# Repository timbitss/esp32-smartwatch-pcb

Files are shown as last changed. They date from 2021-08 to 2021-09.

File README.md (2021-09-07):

# ESP32 Smartwatch PCB

## Blinky Test

Blinky

## Schematic

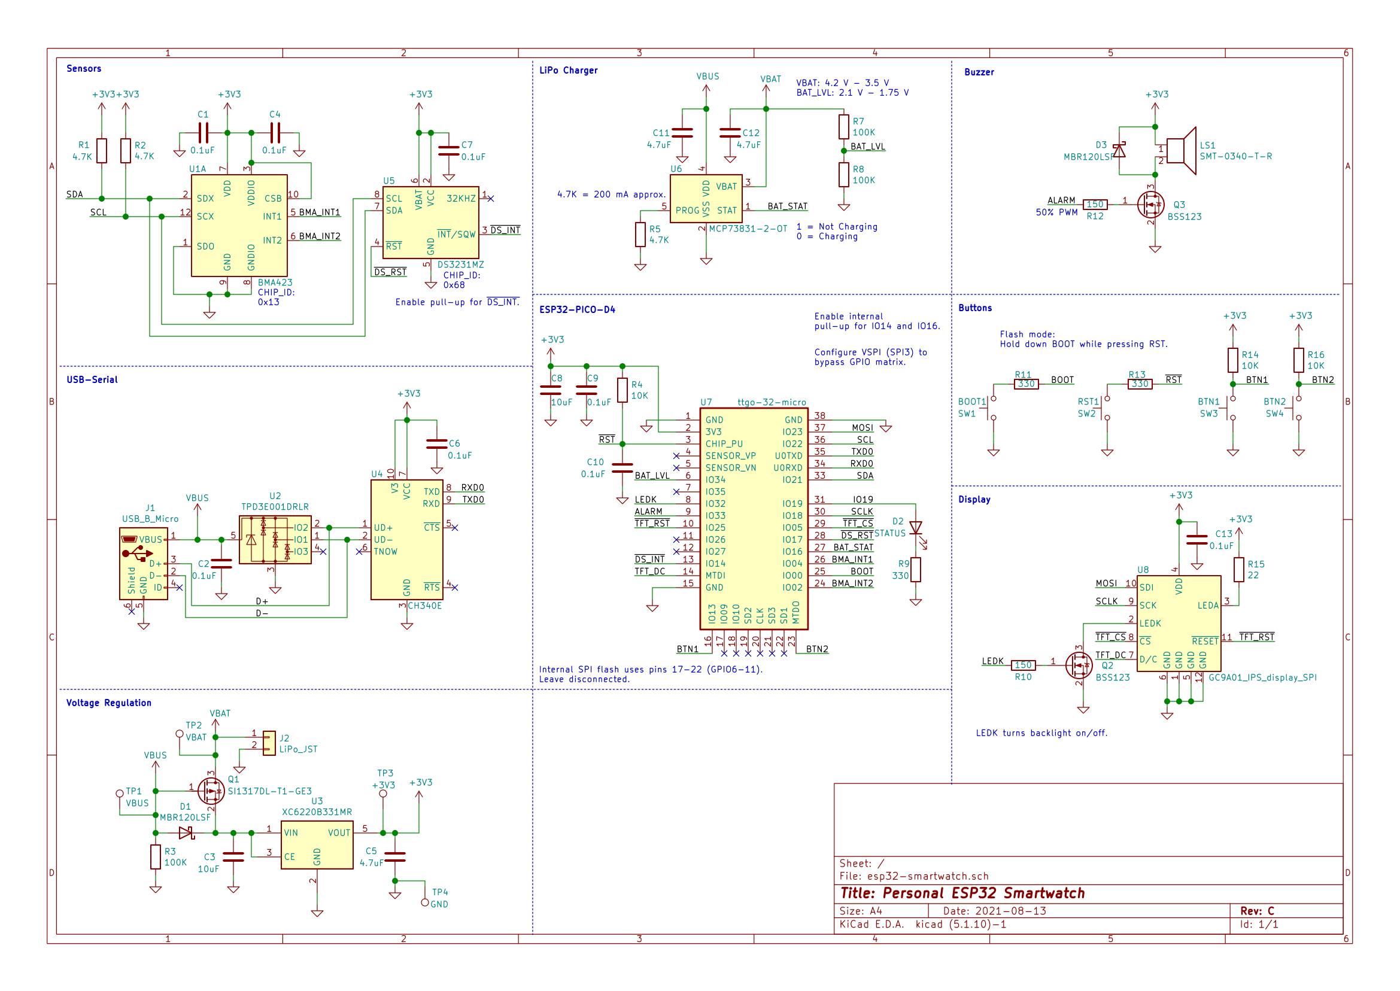
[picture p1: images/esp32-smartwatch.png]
Schematic


## All Layers

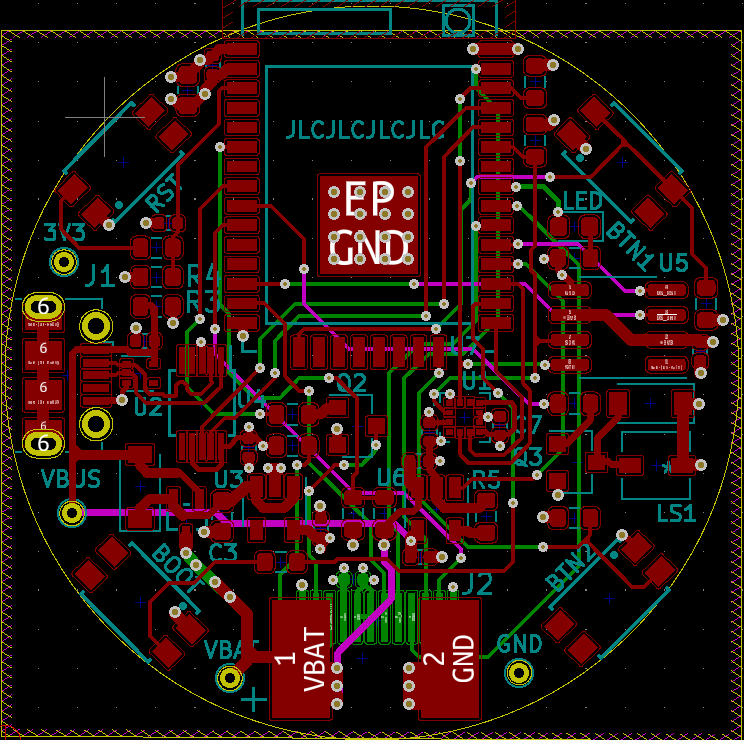
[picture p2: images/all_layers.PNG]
All layers


## Top Layer: Signal

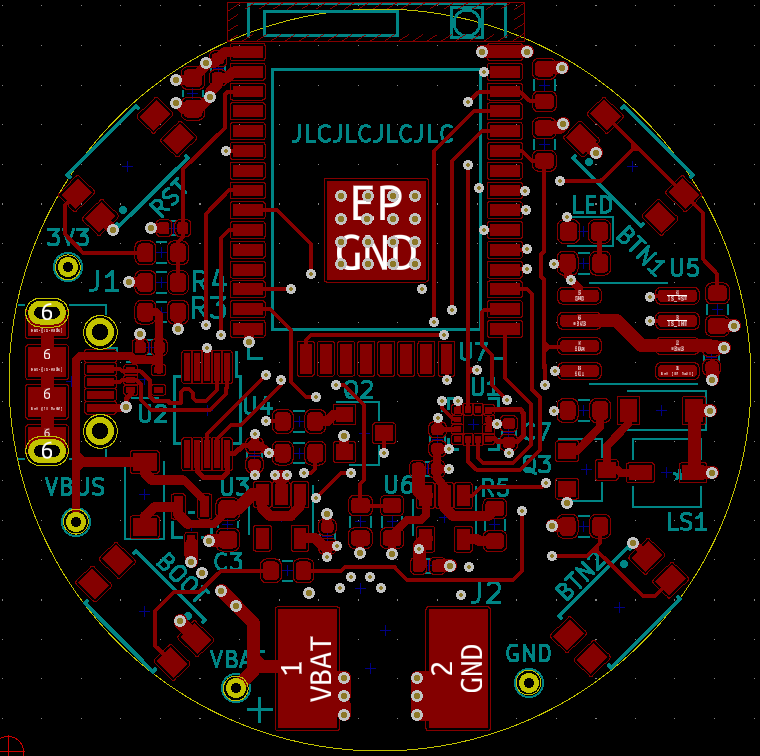
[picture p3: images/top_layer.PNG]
Top layer


## Inner Layer 1: GND

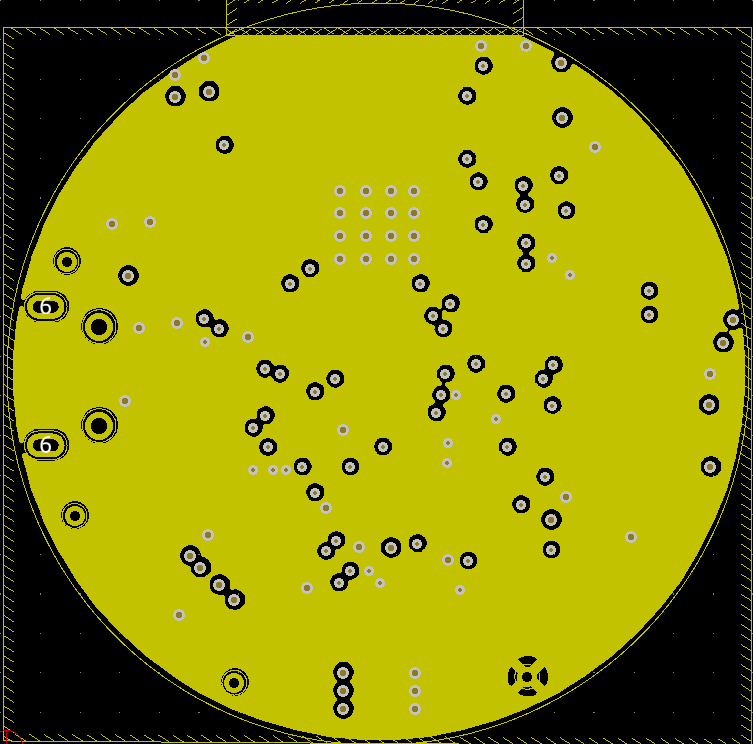
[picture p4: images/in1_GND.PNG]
Inner layer 1


## Inner Layer 2: VCC + Signal

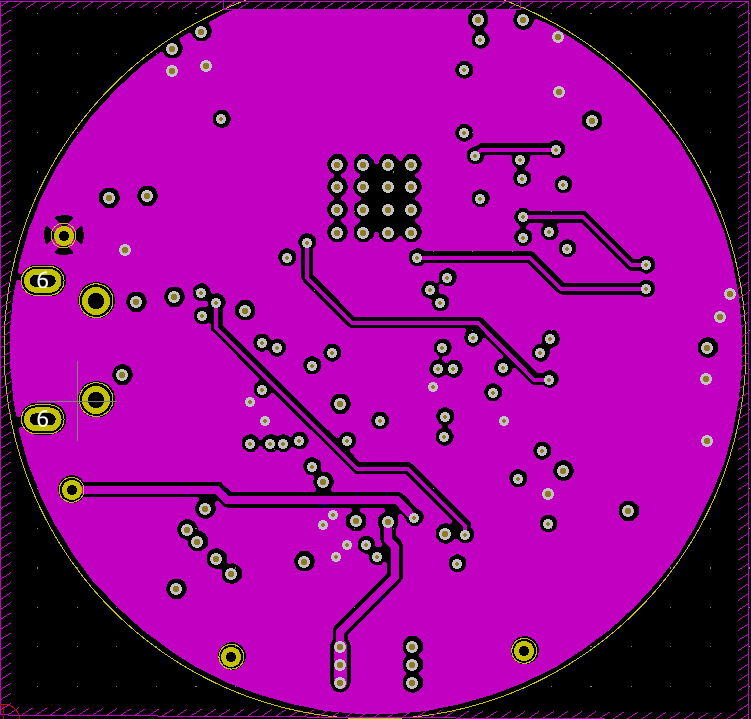
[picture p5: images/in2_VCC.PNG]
Inner layer 2


## Bottom Layer: Signal

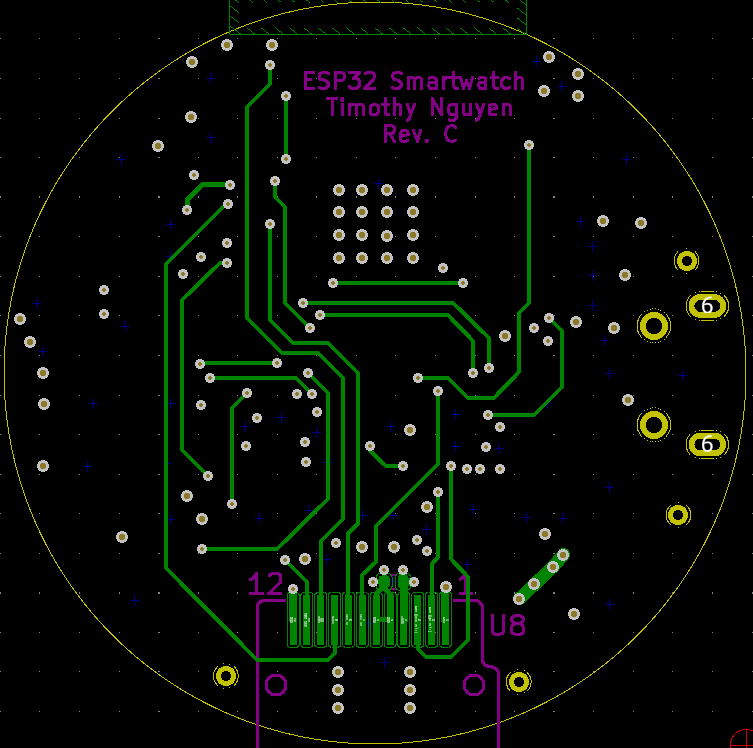
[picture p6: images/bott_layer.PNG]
Bottom layer


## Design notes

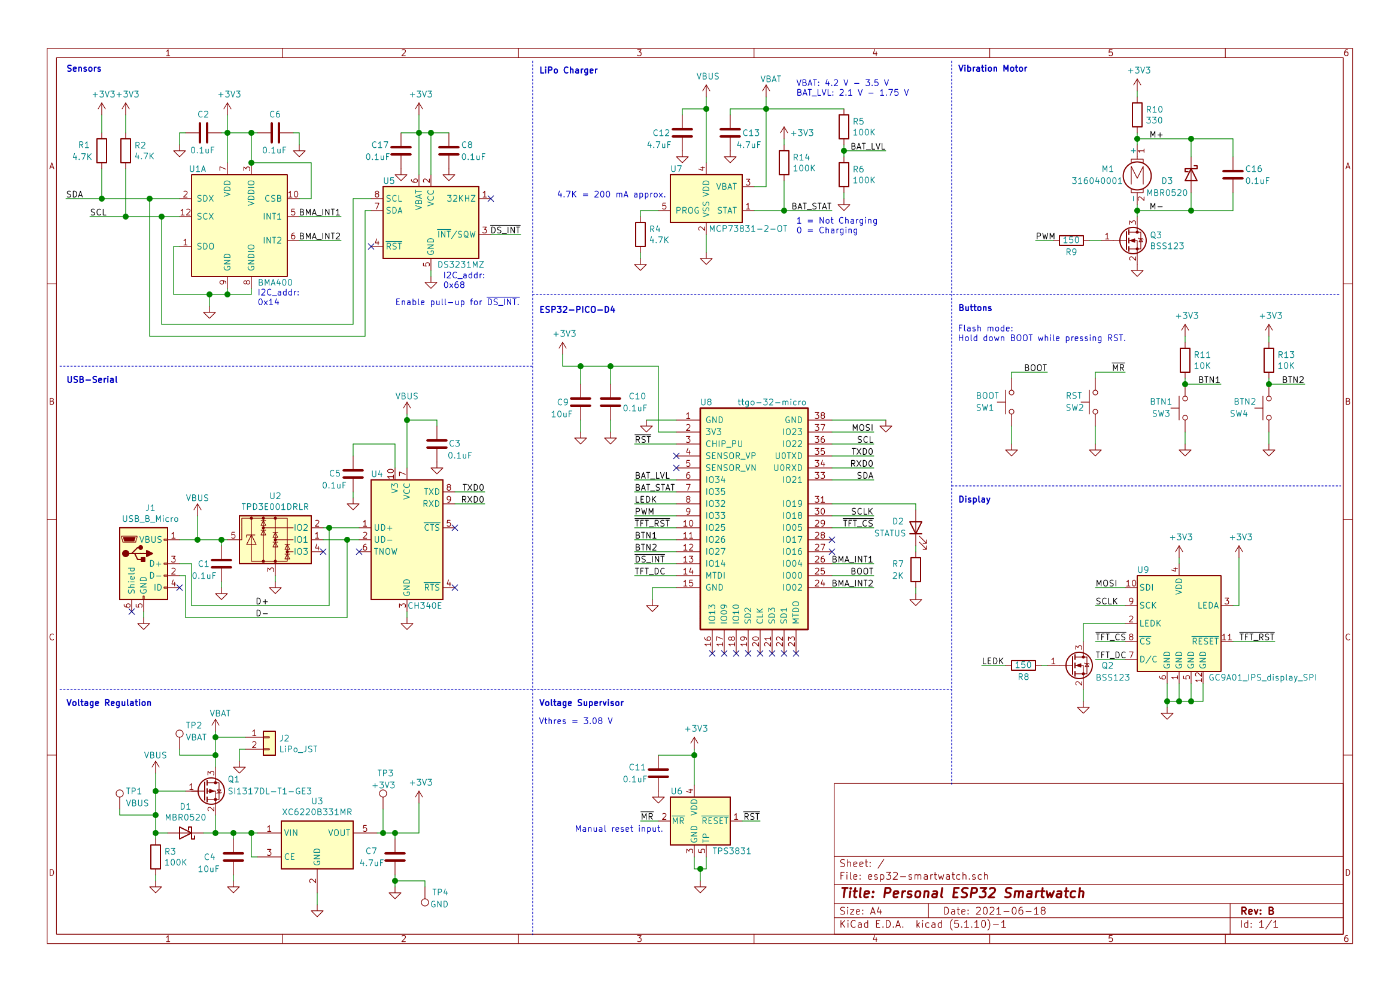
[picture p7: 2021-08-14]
images/esp32-smartwatch-1.png

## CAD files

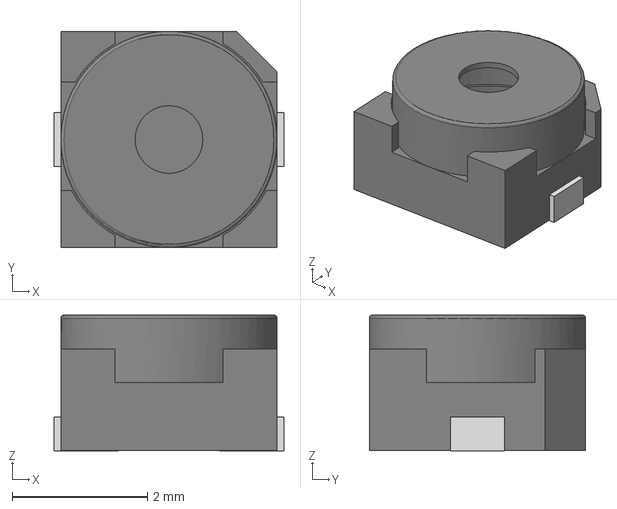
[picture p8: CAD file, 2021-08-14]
3D-models/SMT-0340-T-R.stp
3.40 x 3.20 x 2.01 mm
Lower Housing
Upper Housing

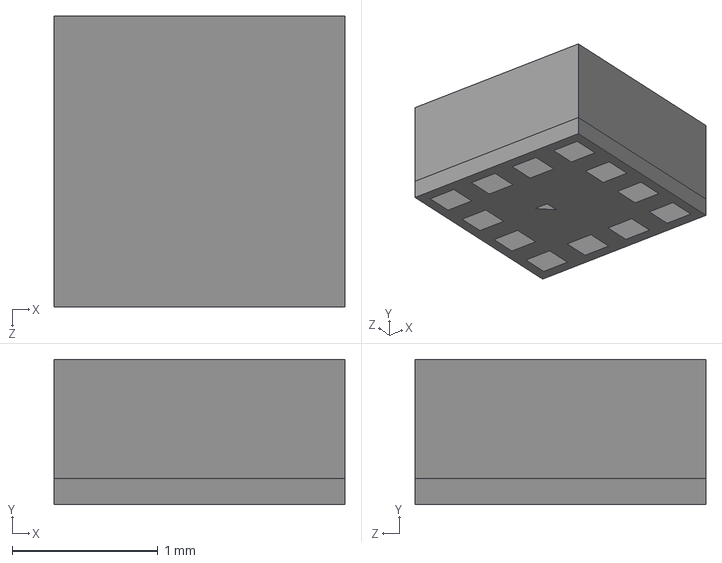
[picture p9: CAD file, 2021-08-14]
3D-models/IC_BMA400.step
2.00 x 1.00 x 2.00 mm

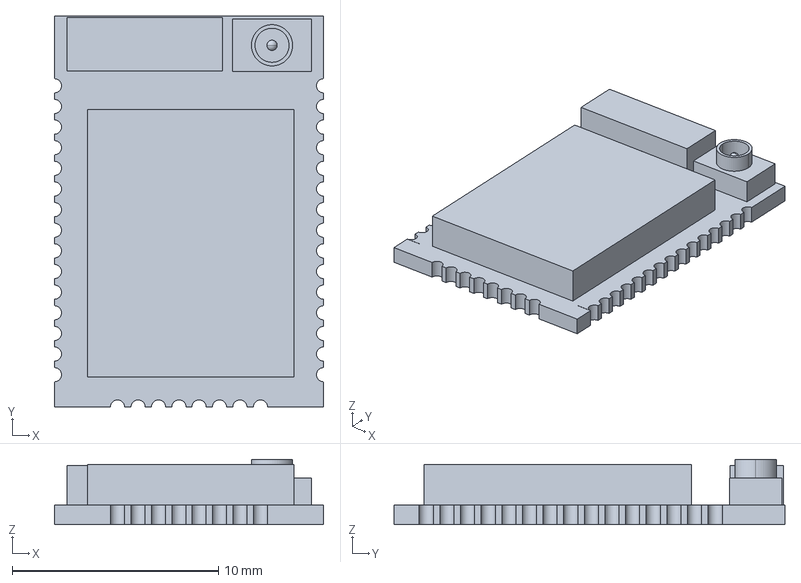
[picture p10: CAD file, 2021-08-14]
3D-models/ttgo-micro32.stp
13.1 x 18.9 x 3.15 mm

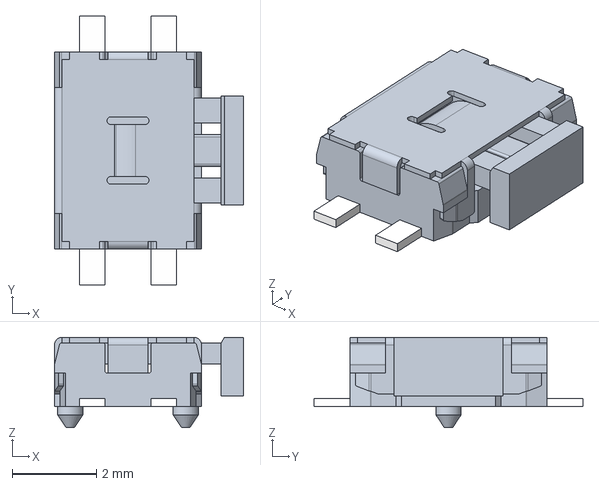
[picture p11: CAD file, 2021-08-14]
3D-models/Tactile_switch.stp
4.50 x 6.40 x 2.15 mm

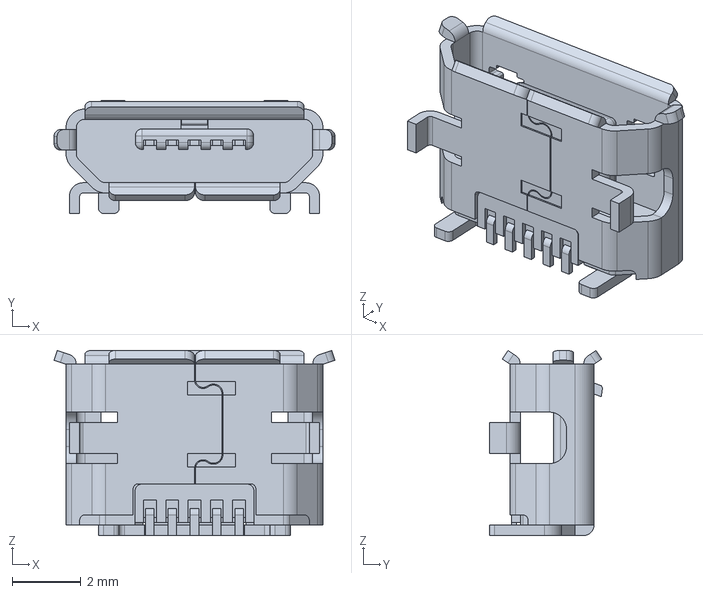
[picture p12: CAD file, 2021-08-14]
3D-models/1050170001.stp
8.20 x 3.30 x 5.40 mm

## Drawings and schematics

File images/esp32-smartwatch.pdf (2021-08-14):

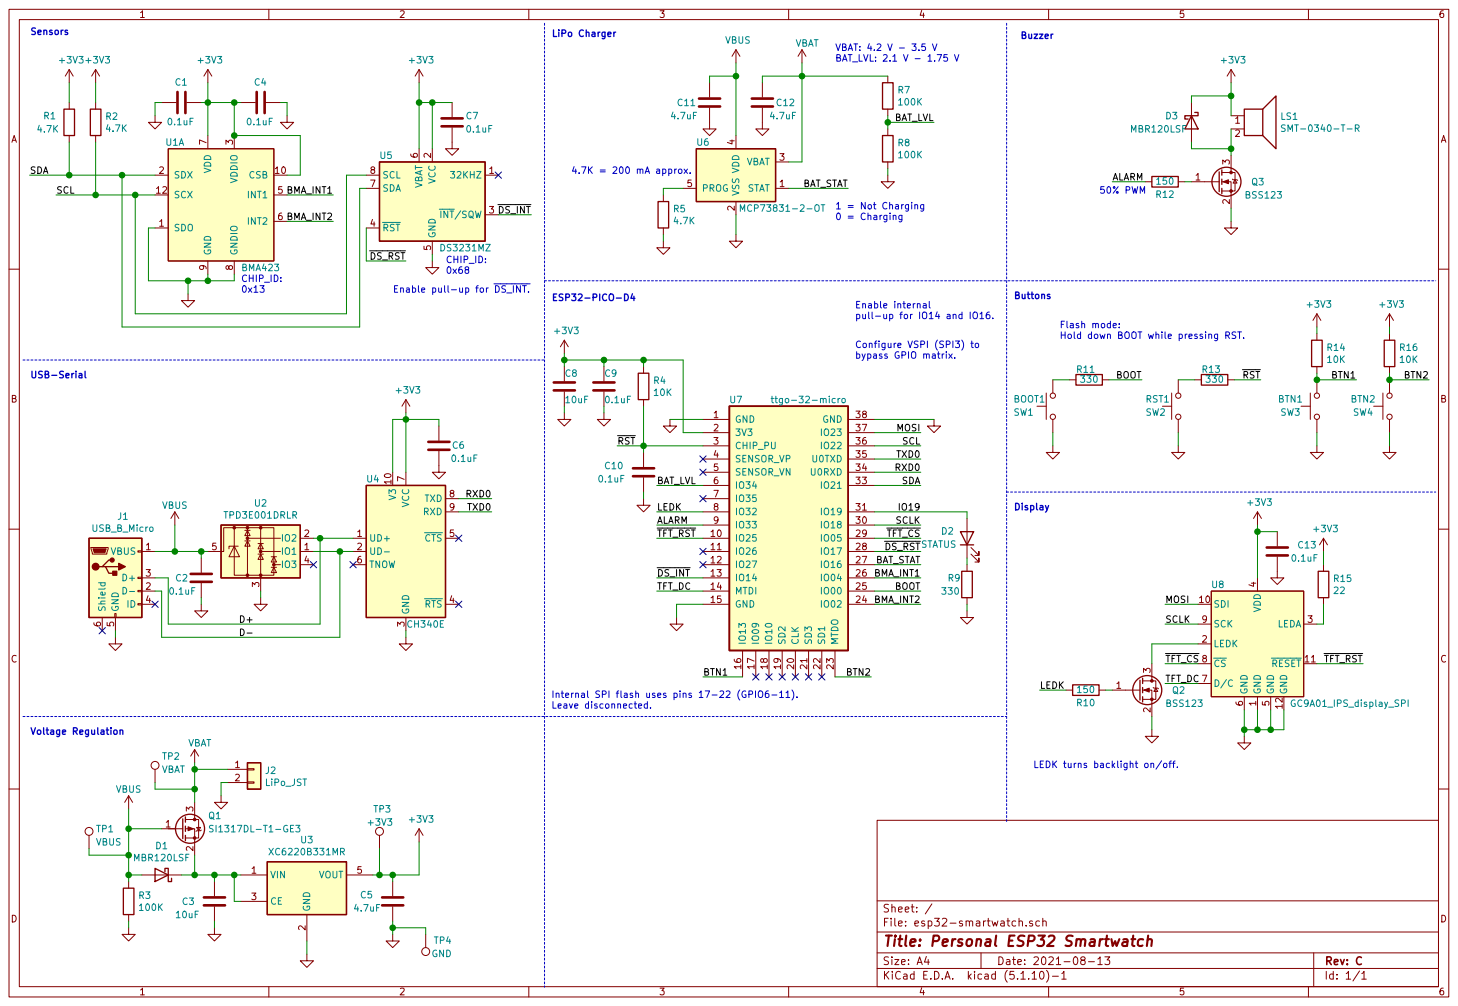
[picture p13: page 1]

3 RTS 4 CTS 5 TNOW 6 VCC

File: esp32-smartwatch.sch Sheet: / C2

Id: 1/1 Title: Personal ESP32 Smartwatch

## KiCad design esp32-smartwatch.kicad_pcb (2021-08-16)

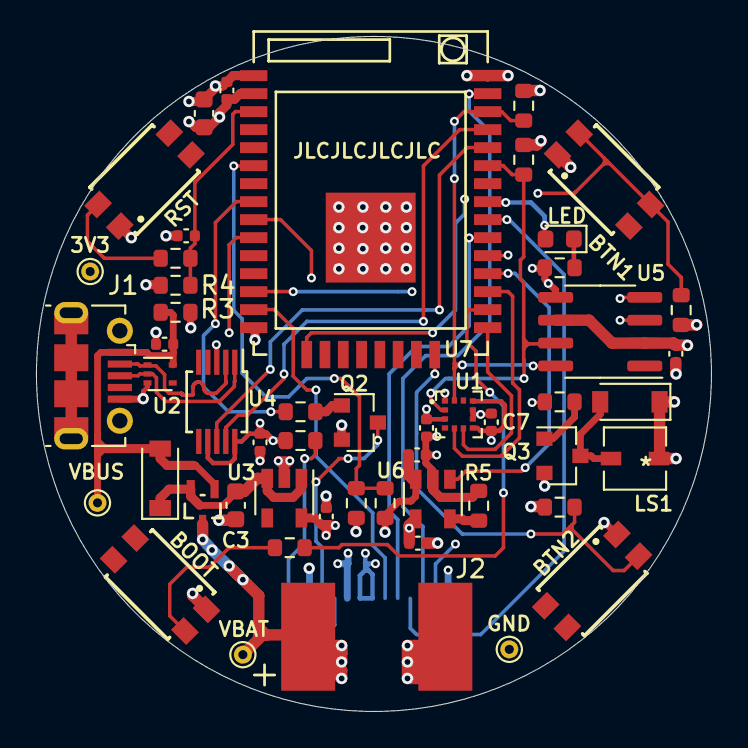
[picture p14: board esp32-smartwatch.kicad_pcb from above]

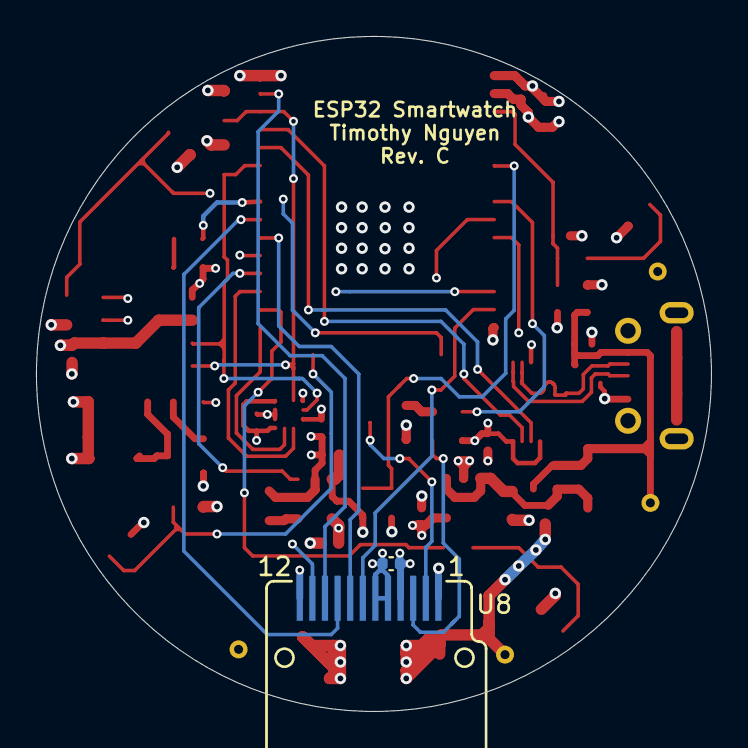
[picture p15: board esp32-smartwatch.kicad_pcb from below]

Board: 4 copper layers, 37.5 x 37.5 mm, 53 parts (2 on the bottom side), 38 nets.

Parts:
3V3: +3V3; TestPoint_THTPad_D1.0mm_Drill0.5mm
BOOT: SW1; switch
BTN1: SW3; switch
BTN2: SW4; switch
C1, C2, C4, C6, C7, C9, C10, C13: 0.1uF; C_0402_1005Metric
C3, C8: 10uF; C_0603_1608Metric
C5, C11, C12: 4.7uF; C_0402_1005Metric
D1, D3: MBR120LSF; D_SOD-123
GND: GND; TestPoint_THTPad_D1.0mm_Drill0.5mm
J1: USB_B_Micro; USB_Micro-B_Molex-105017-0001
J2: LiPo_JST; Custom_pad
LED: STATUS; LED_0603_1608Metric
LS1: ‎SMT-0340-T-R‎; SMT-0340-T-R
Q1: SI1317DL-T1-GE3; SOT65P210X110-3N
Q2, Q3: BSS123; SOT-23
R1, R2, R5: 4.7K; R_0603_1608Metric
R3, R7, R8: 100K; R_0603_1608Metric
R4, R14, R16: 10K; R_0603_1608Metric
R9, R11, R13: 330; R_0603_1608Metric
R10, R12: 150; R_0603_1608Metric
R15: 22; R_0603_1608Metric
RST: SW2; switch
U1: BMA423; IC_BMA400
U2: TPD3E001DRLR; SOT-553
U3: XC6220B331MR; SOT-23-5
U4: CH340E; MSOP-10_3x3mm_P0.5mm
U5: DS3231MZ; SOIC-8_3.9x4.9mm_P1.27mm
U6: MCP73831-2-OT; SOT-23-5
U7: ttgo-32-micro
U8: GC9A01_IPS_display_SPI; GC9A01_IPS_display_under
VBAT: VBAT; TestPoint_THTPad_D1.0mm_Drill0.5mm
VBUS: VBUS; TestPoint_THTPad_D1.0mm_Drill0.5mm

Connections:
+3V3: 3V3.1, C1.2, C4.1, C5.1, C6.2, C7.1, C8.1, C9.1, C13.1, D3.1, LS1.1, R1.1, R2.1, R4.1, R14.1, R15.1, R16.1, U1.3, U1.7, U1.10, U3.5, U4.7, U4.10, U5.2, U5.6, U7.2, U8.4
/ALARM: R12.1, U7.9
/BAT_LVL: R7.2, R8.1, U7.6
/BAT_STAT: U6.1, U7.27
/BMA_INT1: U1.5, U7.26
/BMA_INT2: U1.6, U7.24
/BOOT: R11.2, U7.25
/BTN1: BTN1.2, BTN1.4, R14.2, U7.16
/BTN2: BTN2.2, R16.2, U7.23
/D+: J1.3, U2.2, U4.1
/D-: J1.2, U2.1, U4.2
/IO19: LED.2, U7.31
/LEDK: R10.1, U7.8
/MOSI: U7.37, U8.10
/RXD0: U4.8, U7.34
/SCL: R2.2, U1.12, U5.8, U7.36
/SCLK: U7.30, U8.9
/SDA: R1.2, U1.2, U5.7, U7.33
/TFT_DC: U7.14, U8.7
/TXD0: U4.9, U7.35
/~DS_INT: U5.3, U7.13
/~DS_RST: U5.4, U7.28
/~RST: C10.1, R4.2, R13.2, U7.3
/~TFT_CS: U7.29, U8.8
/~TFT_RST: U7.10, U8.11
GND: BOOT.1, BTN1.1, BTN2.1, C1.1, C2.2, C3.2, C4.2, C5.2, C6.1, C7.2, C8.2, C9.2, C10.2, C11.2, C12.2, C13.2, GND.1, J1.5, J2.2, Q2.2, Q3.2, R3.2, R5.2, R8.2, R9.2, RST.1, U1.1, U1.8, U1.9, U2.3, U3.2, U4.3, U5.5, U6.2, U7.1, U7.15, U7.38, U7.EP, U8.1, U8.5, U8.6, U8.12
unnamed: BOOT.2, R11.1
unnamed: C3.1, D1.1, Q1.2, U3.1, U3.3
unnamed: LED.1, R9.1
unnamed: D3.2, LS1.2, Q3.3
unnamed: Q2.1, R10.2
unnamed: Q2.3, U8.2
unnamed: Q3.1, R12.2
unnamed: R5.1, U6.5
unnamed: R13.1, RST.2
unnamed: R15.2, U8.3
VBAT: C12.1, J2.1, Q1.3, R7.1, U6.3, VBAT.1
VBUS: C2.1, C11.1, D1.2, J1.1, Q1.1, R3.1, U2.5, U6.4, VBUS.1

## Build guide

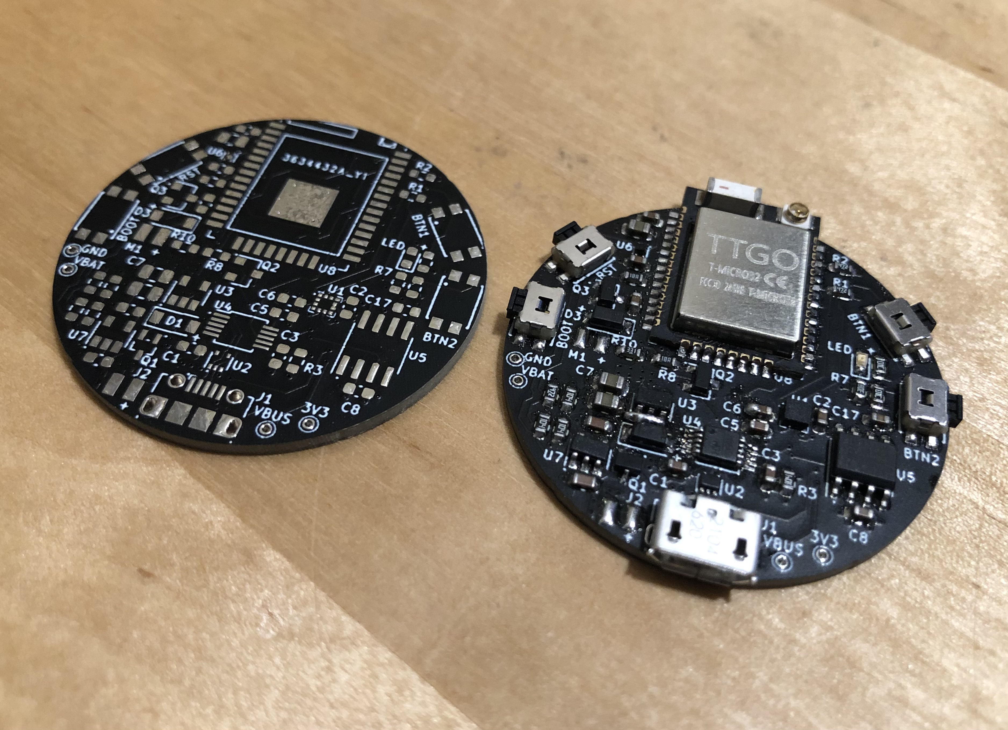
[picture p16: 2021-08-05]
images/manufactured_pcb.jpg

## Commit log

2021-06-26 Added KiCAD files
    [esp32-smartwatch.kicad_pcb, esp32-smartwatch.sch]
2021-08-05 updated images
    [esp32-smartwatch-B_Cu.gbl, esp32-smartwatch-B_Mask.gbs, esp32-smartwatch-B_Paste.gbp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]
2021-08-14 Redoing PCB
    [1050170001.stp, IC_BMA400.step, SMT-0340-T-R.stp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]
2021-08-14 Revising PCB
2021-08-14 Revised schematic
    [esp32-smartwatch.sch]
2021-08-16 PCB layout Rev C
    [esp32-smartwatch-B_Cu.gbl, esp32-smartwatch-B_Mask.gbs, esp32-smartwatch-B_Paste.gbp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]

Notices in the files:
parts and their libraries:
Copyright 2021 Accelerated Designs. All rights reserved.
